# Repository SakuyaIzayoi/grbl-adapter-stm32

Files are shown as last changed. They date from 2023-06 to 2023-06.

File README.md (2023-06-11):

# grbl-adapter-stm32
GRBL Adapter using an STM32 BluePill

### Stepcraft D600 GRBL Settings
| Setting | Value | Description |
| --- | --- | --- |
| $0 | 50 | Step pulse time |
| $1 | 100 | Step idle delay |
| $2 | 0 | Step pulse invert |
| $3 | 0 | Step direction invert |
| $4 | 1 | Invert step enable pin |
| $5 | 1 | Invert limit pins |
| $6 | 1 | Invert probe pin |
| $10 | 1 | Status report options |
| $11 | 0.010 | Junction deviation |
| $13 | 0 | Report in inches |
| $20 | 1 | Soft limits enable |
| $21 | 1 | Hard limits enable |
| $22 | 1 | Homing cycle enable |
| $23 | 1 | Homing direction invert |
| $24 | 120.000 | Homing locate feed rate |
| $25 | 900.000 | Homing search seek rate |
| $26 | 250 | Homing switch debounce delay |
| $27 | 1.000 | Homing switch pull-off distance |
| $30 | 1000 | Maximum spindle speed |
| $31 | 0 | Minimum spindle speed |
| $32 | 0 | Laser-mode enable |
| $100 | 133.333 | X-ais travel resolution |
| $101 | 133.333 | Y-ais travel resolution |
| $102 | 133.333 | Z-ais travel resolution |
| $103 | 133.333 | A-ais travel resolution |
| $110 | 800.000 | X-axis maximum rate |
| $111 | 800.000 | Y-axis maximum rate |
| $112 | 800.000 | Z-axis maximum rate |
| $113 | 800.000 | A-axis maximum rate |
| $120 | 5.000 | X-axis acceleration |
| $121 | 5.000 | Y-axis acceleration |
| $122 | 5.000 | Z-axis acceleration |
| $123 | 5.000 | A-axis acceleration |
| $130 | 300.000 | X-axis maximum travel |
| $131 | 420.000 | Y-axis maximum travel |
| $132 | 140.000 | Z-axis maximum travel |
| $133 | 100.000 | A-axis maximum travel |

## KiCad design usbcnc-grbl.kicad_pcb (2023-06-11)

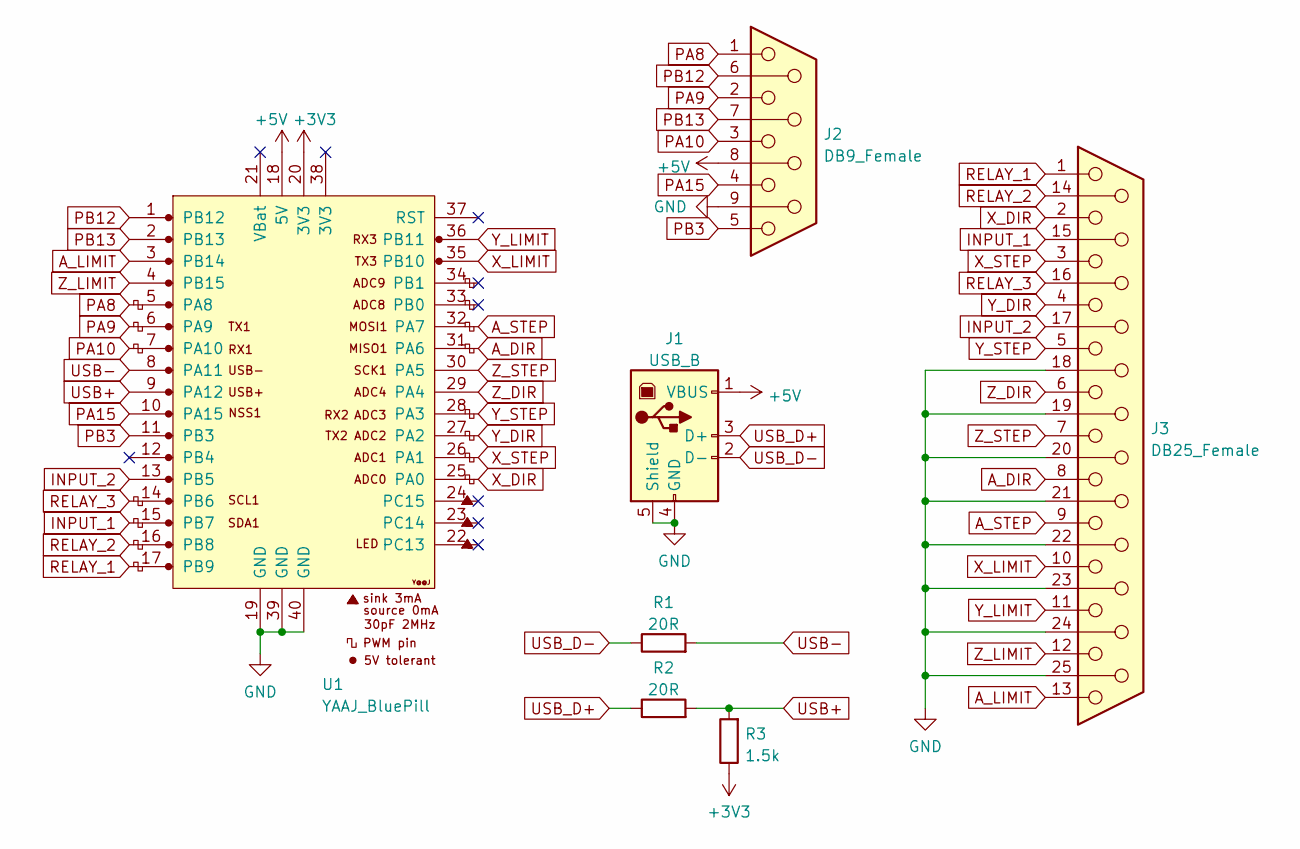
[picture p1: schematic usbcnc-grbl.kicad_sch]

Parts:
J1: USB_B; USB_B_OST_USB-B1HSxx_Horizontal
J2: DB9_Female; DSUB-9_Female_EdgeMount_P2.77mm
J3: DB25_Female; DSUB-25_Female_EdgeMount_P2.77mm
R1, R2: 20R; R_0805_2012Metric_Pad1.20x1.40mm_HandSolder
R3: 1.5k; R_0805_2012Metric_Pad1.20x1.40mm_HandSolder
U1: YAAJ_BluePill; YAAJ_BluePill_2

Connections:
+3V3: R3.1, U1.20 (3V3)
+5V: J1.1 (VBUS), J2.8, U1.18 (5V)
A_DIR: J3.8, U1.31 (PA6)
A_LIMIT: J3.13, U1.3 (PB14)
A_STEP: J3.9, U1.32 (PA7)
GND: J1.4 (GND), J1.5 (Shield), J2.9, J3.18, J3.19, J3.20, J3.21, J3.22, J3.23, J3.24, J3.25, U1.19 (GND), U1.39 (GND), U1.40 (GND)
INPUT_1: J3.15, U1.15 (PB7)
INPUT_2: J3.17, U1.13 (PB5)
PA8: J2.1, U1.5 (PA8)
PA9: J2.2, U1.6 (PA9)
PA10: J2.3, U1.7 (PA10)
PA15: J2.4, U1.10 (PA15)
PB3: J2.5, U1.11 (PB3)
PB12: J2.6, U1.1 (PB12)
PB13: J2.7, U1.2 (PB13)
RELAY_1: J3.1, U1.17 (PB9)
RELAY_2: J3.14, U1.16 (PB8)
RELAY_3: J3.16, U1.14 (PB6)
USB+: R2.2, R3.2, U1.9 (PA12)
USB-: R1.2, U1.8 (PA11)
USB_D+: J1.3 (D+), R2.1
USB_D-: J1.2 (D-), R1.1
X_DIR: J3.2, U1.25 (PA0)
X_LIMIT: J3.10, U1.35 (PB10)
X_STEP: J3.3, U1.26 (PA1)
Y_DIR: J3.4, U1.27 (PA2)
Y_LIMIT: J3.11, U1.36 (PB11)
Y_STEP: J3.5, U1.28 (PA3)
Z_DIR: J3.6, U1.29 (PA4)
Z_LIMIT: J3.12, U1.4 (PB15)
Z_STEP: J3.7, U1.30 (PA5)

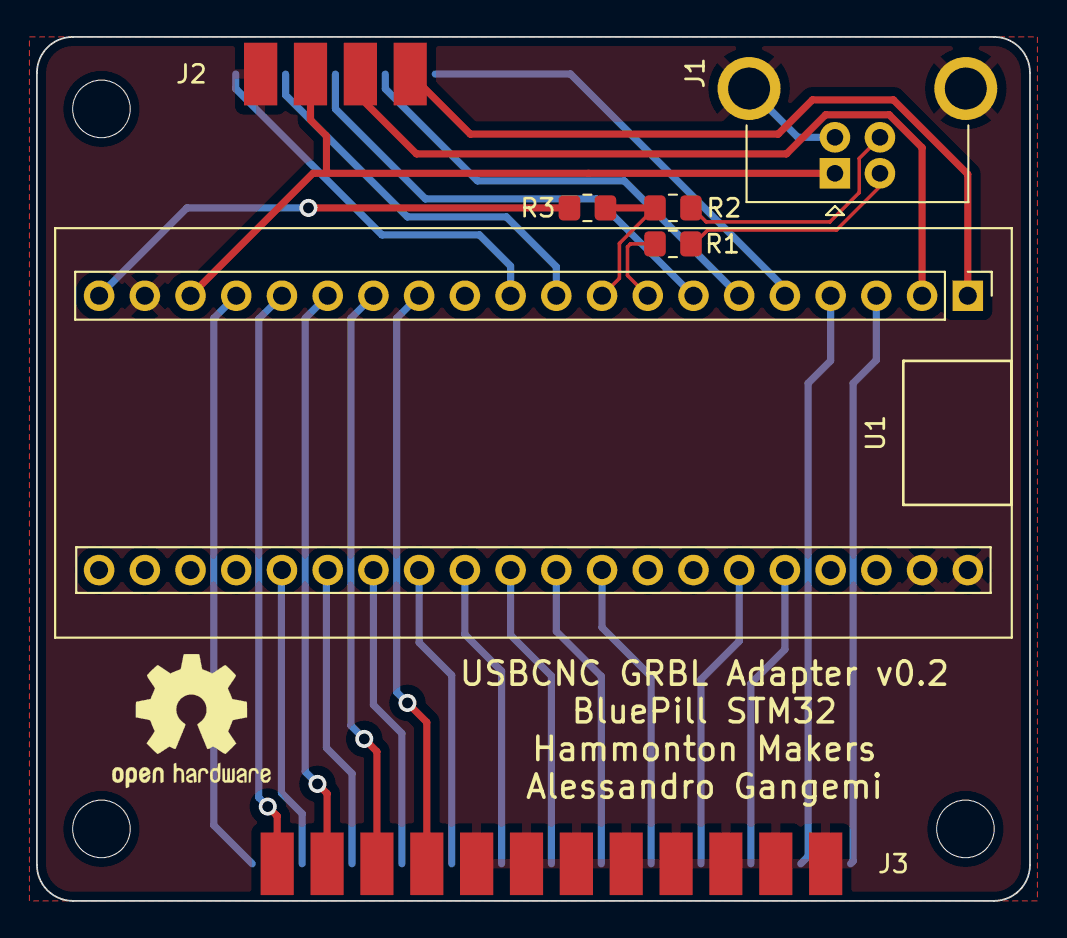
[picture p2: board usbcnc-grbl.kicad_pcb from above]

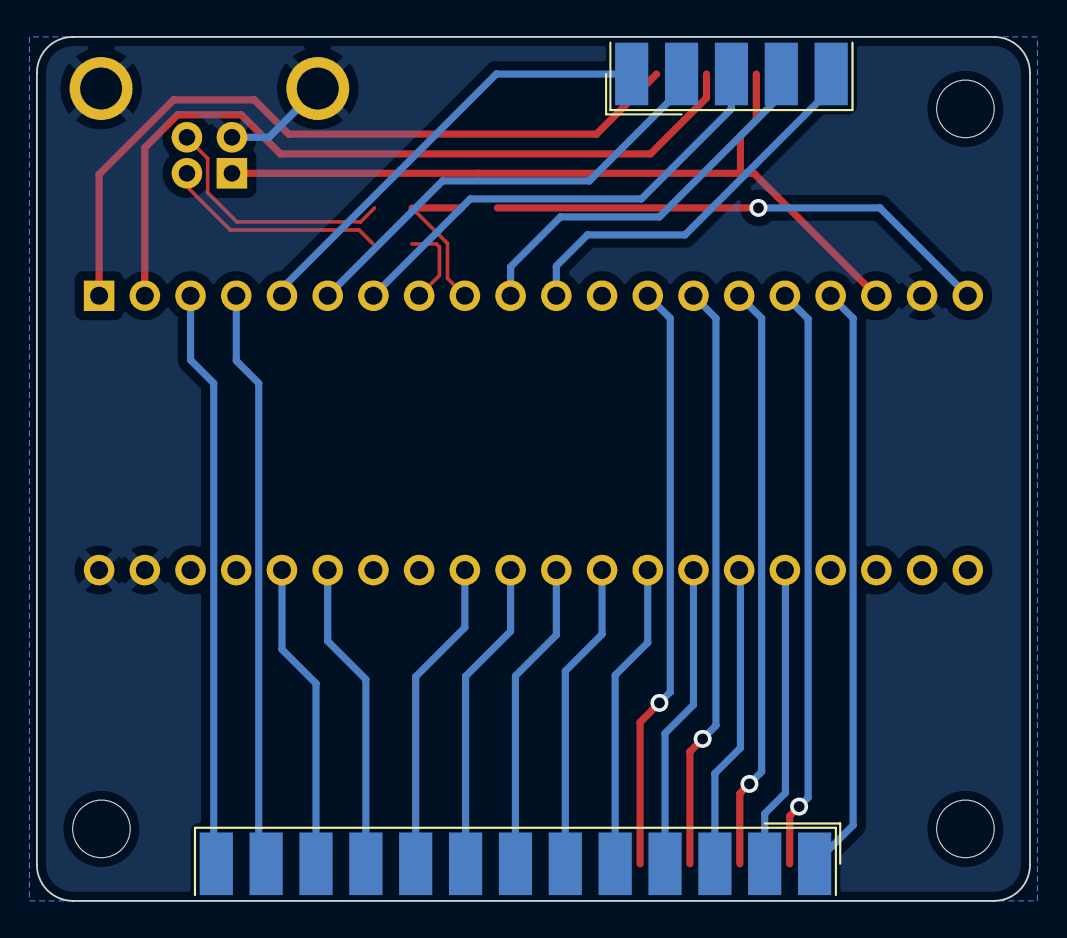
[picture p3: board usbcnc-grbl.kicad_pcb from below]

Board: 2 copper layers, 55.2 x 48.0 mm, 7 parts (2 on the bottom side), 31 nets.

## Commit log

2023-05-27 Initial commit
    Version 0.2 with USB resistors
    [usbcnc-grbl.kicad_pcb, usbcnc-grbl.kicad_sch]
2023-05-27 Fix pullup on USB
    [usbcnc-grbl.kicad_pcb, usbcnc-grbl.kicad_sch]
2023-06-11 Update to Kicad 7
    [usbcnc-grbl.kicad_pcb, usbcnc-grbl.kicad_sch]
